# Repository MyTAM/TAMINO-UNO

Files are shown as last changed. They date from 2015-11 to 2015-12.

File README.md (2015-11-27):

# TAMINO-UNO
Docs and Drivers for the TAMINO UNO board
-------------------

[TAMINO-UNO  
*TAMINO UNO (TAMINO01)*](http://www.tuttoamenoshop.it/epages/84141.sf/it_IT/?ObjectPath=/Shops/84141/Products/TAMINO01)

TAMINO UNO is an Arduino(TM) like development board fully compatible, designed in Italy.

License Information
-------------------

The hardware design and firmware are released under [Creative Commons Share-alike 3.0](http://creativecommons.org/licenses/by-sa/3.0/).

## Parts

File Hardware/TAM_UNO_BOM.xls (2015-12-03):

AD | 6x1F-H8.5 | PINHD-1X6 | 1
C1 | 100n | C0603 | 1
C2 | 100n | C0603 | 1
C3 | 100nF | C0603 | 1
C4 | 100n | C0603 | 1
C5 | 100n | C0603 | 1
C6 | 100n | C0603 | 1
C7 | 100nF | C0603 | 1
C8 | 100n | C0603 | 1
C9 | 22p | C0603 | 1
C10 | 22p | C0603 | 1
C11 | 22p | C0603 | 1
C12 | 22p | C0603 | 1
D1 | M7 | DIODE-SMB | 1
D2 | CD1206-S01575 | DIODE-MINIMELF | 1
IC1 | LMV358M | SSO-8 | 1
ICSP | 3x2 | PINHD-2X3 | 1
IOH | 10x1F-H8.5 | PINHD-1X10_ARD | 1
IOL | 8x1F-H8.5 | PINHD-1X8 | 1
L | YELLOW | LED0805 | 1
ON | GREEN | LED0805 | 1
PC1 | 47u | CPOL-EUD | 1
PC2 | 47u | CPOL-EUD | 1
POWER | 8x1F-H8.5 | PINHD-1X8 | 1
Q1 | 12MHz | CRYSTALSM49 | 1
Q2 | 16MHz | CRYSTALSM49 | 1
R1 | 470R | R0603 | 1
R2 | 10k | R0603 | 1
R3 | 10k | R0603 | 1
R4 | 10k | R0603 | 1
R5 | 470R | R0603 | 1
R6 | 470R | R0603 | 1
R7 | 1k | R0603 | 1
R8 | 1k | R0603 | 1
R9 | 10k | R0603 | 1
R10 | 1M | R0603 | 1
R11 | 470R | R0603 | 1
RESET | TS42 BUTTON | TS42 | 1
RX | YELLOW LED | LED0805 | 1
T1 | FDN340P | PMOSSOT23 | 1
T2 | SS8055 | SOT23-EBC | 1
T3 | SS8055 | SOT23-EBC | 1
TX | YELLOW LED | LED0805 | 1
U$1 | CH340G | SSO-14 | 1
U1 | NCP1117ST50T3G | DPAK | 1
U2 | RT9013-33GB | SOT-23-5 | 1
X1 | POWERSUPPLY_DC21MMX | POWERSUPPLY_DC21MMX | 1
X2 | USB-B_TH | PN61729 | 1
Z1 | SOCKET DIL 28 |  | 1
PCB |  |  | 1
ZU4 | ATMEGA328P-PU | ATMEGA328P-PU | 1

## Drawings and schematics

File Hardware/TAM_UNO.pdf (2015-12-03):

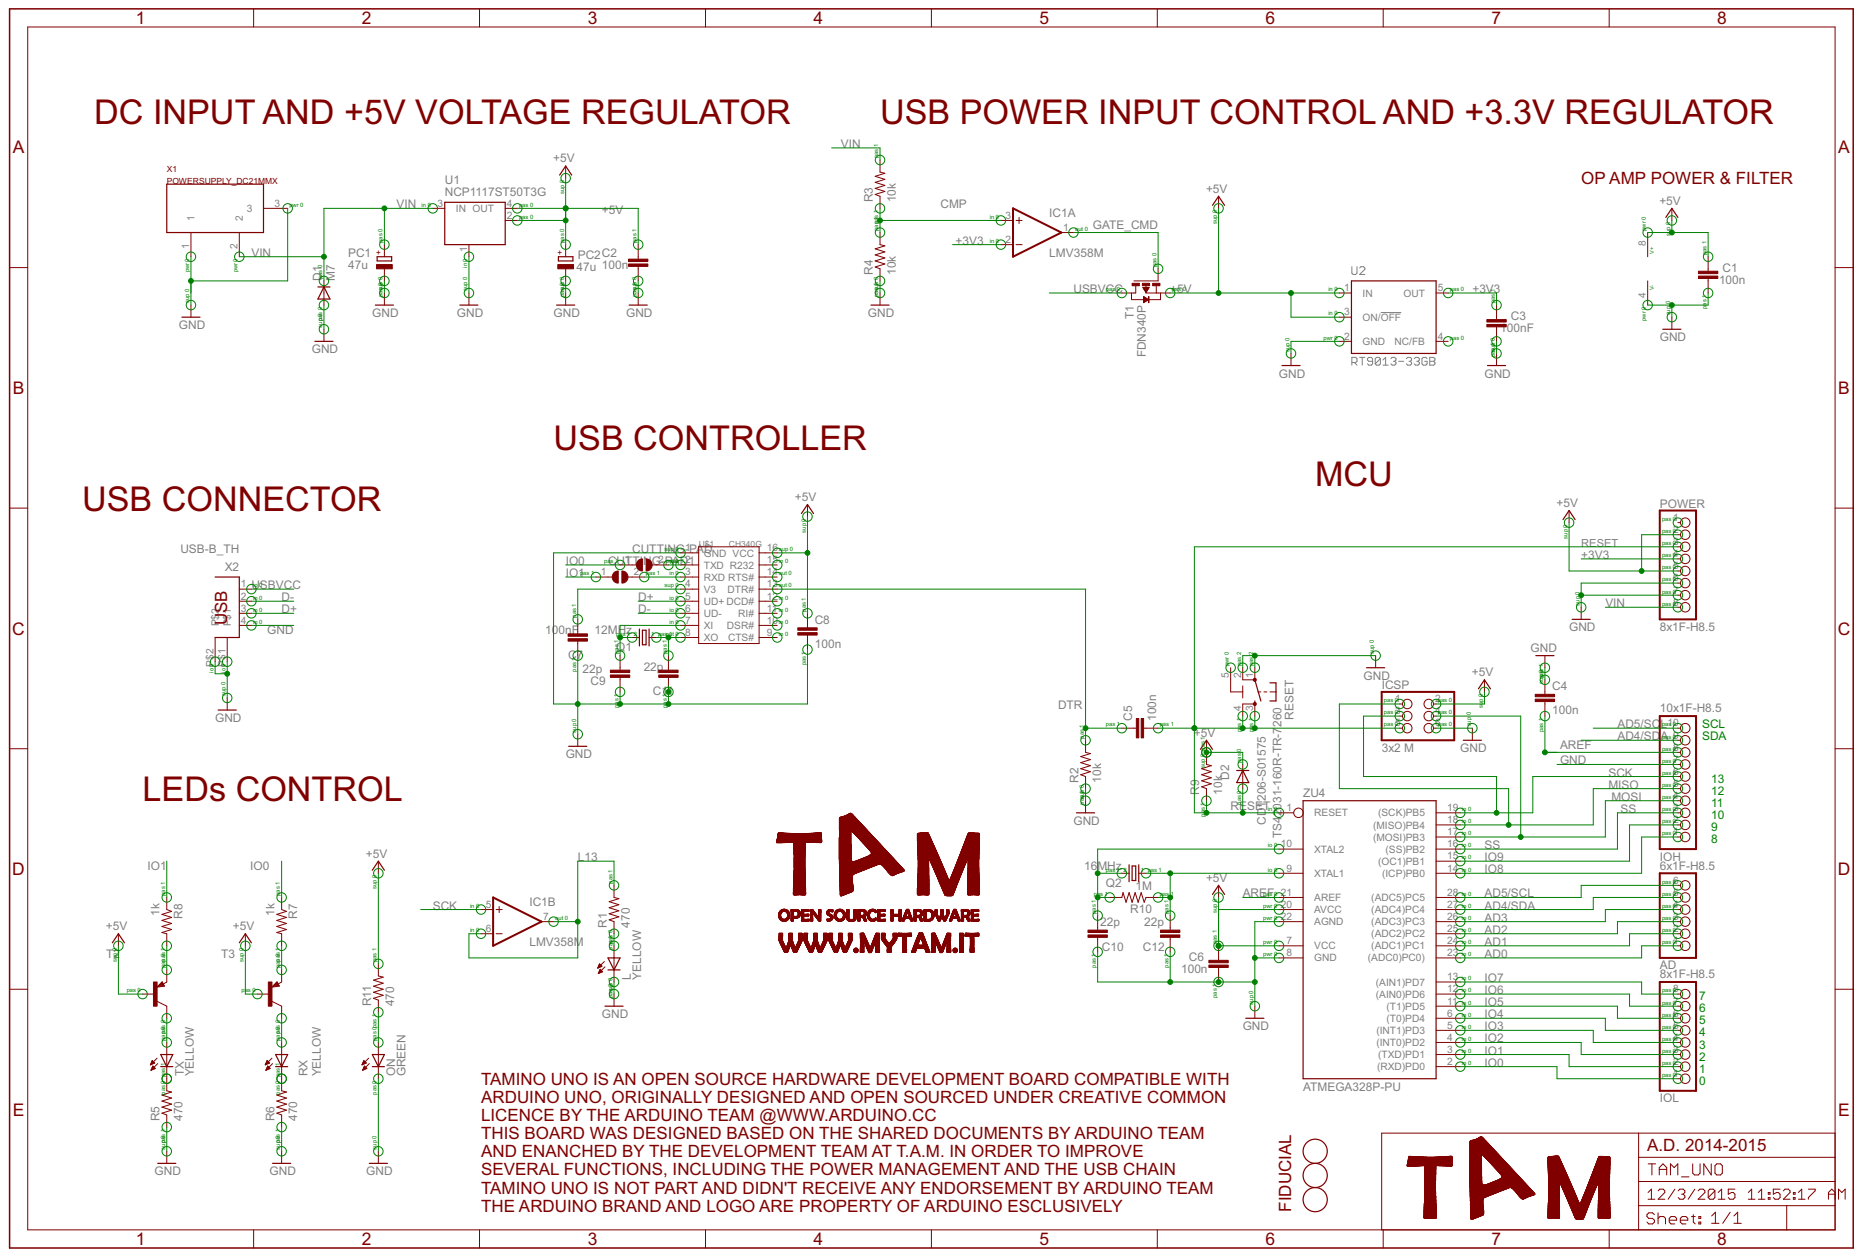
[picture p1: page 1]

pas 1 pas 1

OP AMP POWER & FILTER

pas 0 pas 0 sup 0 sup 0

TAMINO UNO IS AN OPEN SOURCE HARDWARE DEVELOPMENT BOARD COMPATIBLE WITH
ARDUINO UNO, ORIGINALLY DESIGNED AND OPEN SOURCED UNDER CREATIVE COMMON
LICENCE BY THE ARDUINO TEAM @WWW.ARDUINO.CC
THIS BOARD WAS DESIGNED BASED ON THE SHARED DOCUMENTS BY ARDUINO TEAM
AND ENANCHED BY THE DEVELOPMENT TEAM AT T.A.M. IN ORDER TO IMPROVE
SEVERAL FUNCTIONS, INCLUDING THE POWER MANAGEMENT AND THE USB CHAIN
TAMINO UNO IS NOT PART AND DIDN'T RECEIVE ANY ENDORSEMENT BY ARDUINO TEAM
THE ARDUINO BRAND AND LOGO ARE PROPERTY OF ARDUINO ESCLUSIVELY

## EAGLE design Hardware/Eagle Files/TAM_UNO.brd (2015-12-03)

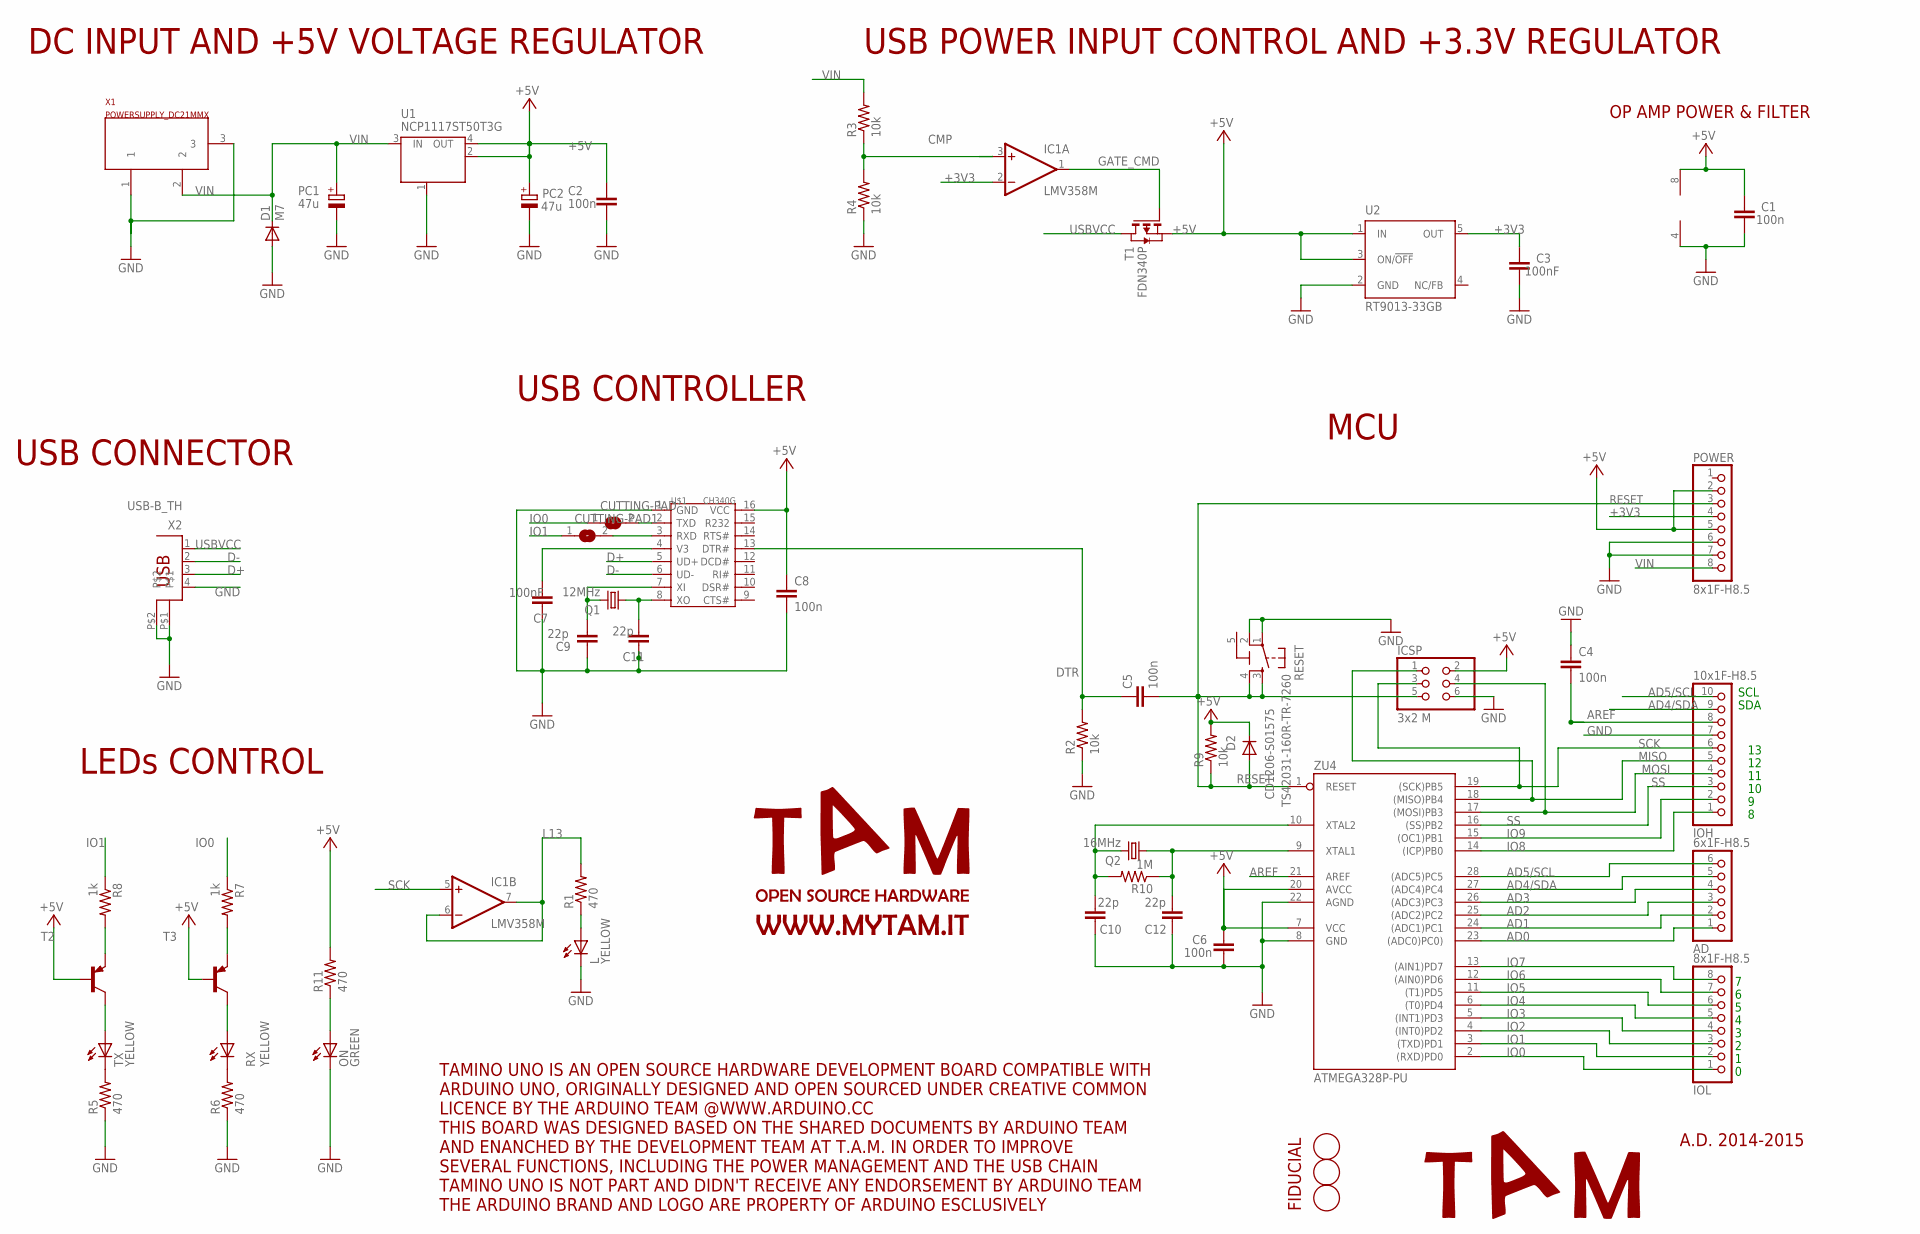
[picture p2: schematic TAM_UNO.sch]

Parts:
AD: 6x1F-H8.5; 1X06
C1, C2, C4, C5, C6, C8: 100n; C0603K
C3, C7: 100nF; C0603K
C9, C10, C11, C12: 22p; C0603K
CUTTING-PAD, CUTTING-PAD1: SJ
D1: M7; SMB
D2: CD1206-S01575; MINIMELF
FD1, FD2, FD3: FIDUCIALMOUNT; FIDUCIA-MOUNT
IC1: LMV358M; SO08
ICSP: 3x2 M; 2X03
IOH: 10x1F-H8.5; 1X10
IOL: 8x1F-H8.5; 1X08
L: YELLOW; CHIP-LED0805
ON: GREEN; CHIP-LED0805
PC1, PC2: 47u; PANASONIC_D
POWER: 8x1F-H8.5; 1X08
Q1: 12MHz; SM49
Q2: 16MHz; SM49
R1, R5, R6, R11: 470; R0603
R2, R3, R4, R9: 10k; R0603
R7, R8: 1k; R0603
R10: 1M; R0603
RESET: TS42031-160R-TR-7260; TS42
RX: YELLOW; CHIP-LED0805
T1: FDN340P; SOT-23
T2, T3: -PNP-SOT23-EBC; SOT23-EBC
TX: YELLOW; CHIP-LED0805
U1: NCP1117ST50T3G; SOT223
U2: RT9013-33GB; SOT23-DBV
U$1: CH340G; SSOP16
X1: POWERSUPPLY_DC21MMX; POWERSUPPLY_DC-21MM
X2: USB-B_TH; PN61729
ZU4: ATMEGA328P-PU; DIL28-3

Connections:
5-GND: RESET.5 (5-GND)
+3V3: C3.2, IC1.2 (-IN), POWER.4, U2.5 (OUT)
+5V: C1.2, C2.2, C6.2, C8.1, D2.C, IC1.8 (V+), ICSP.2, PC2.+, POWER.2, POWER.5, R9.2, R11.2, T1.2 (S), T2.B, T3.B, U1.2 (OUT), U1.4 (OUT), U2.1 (IN), U2.3 (ON/!OFF), U$1.16 (VCC), ZU4.7 (VCC), ZU4.20 (AVCC)
AD0: AD.1, ZU4.23 ((ADC0)PC0))
AD1: AD.2, ZU4.24 ((ADC1)PC1)
AD2: AD.3, ZU4.25 ((ADC2)PC2)
AD3: AD.4, ZU4.26 ((ADC3)PC3)
AD4/SDA: AD.5, IOH.9, ZU4.27 ((ADC4)PC4)
AD5/SCL: AD.6, IOH.10, ZU4.28 ((ADC5)PC5)
AREF: C4.2, IOH.8, ZU4.21 (AREF)
CMP: IC1.3 (+IN), R3.1, R4.2
D+: U$1.5 (UD+), X2.3
D-: U$1.6 (UD-), X2.2
DTR: C5.1, R2.2, U$1.13 (DTR#)
GATE_CMD: IC1.1 (OUT), T1.3 (G)
GND: C1.1, C2.1, C3.1, C4.1, C6.1, C7.2, C8.2, C9.2, C10.2, C11.2, C12.2, D1.A, IC1.4 (V-), ICSP.6, IOH.7, L.C, ON.C, PC1.-, PC2.-, POWER.6, POWER.7, R2.1, R4.1, R5.1, R6.1, RESET.1, RESET.2, U1.1 (GND/ADJ), U2.2 (GND), U$1.1 (GND), X1.1, X1.3, X2.4, X2.P$1, X2.P$2, ZU4.8 (GND), ZU4.22 (AGND)
IO0: CUTTING-PAD.1, IOL.1, R7.1, ZU4.2 ((RXD)PD0)
IO1: CUTTING-PAD1.1, IOL.2, R8.1, ZU4.3 ((TXD)PD1)
IO2: IOL.3, ZU4.4 ((INT0)PD2)
IO3: IOL.4, ZU4.5 ((INT1)PD3)
IO4: IOL.5, ZU4.6 ((T0)PD4)
IO5: IOL.6, ZU4.11 ((T1)PD5)
IO6: IOL.7, ZU4.12 ((AIN0)PD6)
IO7: IOL.8, ZU4.13 ((AIN1)PD7)
IO8: IOH.1, ZU4.14 ((ICP)PB0)
IO9: IOH.2, ZU4.15 ((OC1)PB1)
L13: IC1.6 (-IN), IC1.7 (OUT), R1.2
MISO: ICSP.1, IOH.5, ZU4.18 ((MISO)PB4)
MOSI: ICSP.4, IOH.4, ZU4.17 ((MOSI)PB3)
unnamed: L.A, R1.1
unnamed: C9.1, Q1.2, U$1.7 (XI)
unnamed: ON.A, R11.1
unnamed: C11.1, Q1.1, U$1.8 (XO)
unnamed: R5.2, TX.C
unnamed: R6.2, RX.C
unnamed: R8.2, T2.E
unnamed: R7.2, T3.E
unnamed: T2.C, TX.A
unnamed: RX.A, T3.C
unnamed: C10.1, Q2.2, R10.2, ZU4.10 (XTAL2)
unnamed: C12.1, Q2.1, R10.1, ZU4.9 (XTAL1)
unnamed: CUTTING-PAD.2, U$1.2 (TXD)
unnamed: CUTTING-PAD1.2, U$1.3 (RXD)
RESET: C5.2, D2.A, ICSP.5, POWER.3, R9.1, RESET.3, RESET.4, ZU4.1 (RESET)
SCK: IC1.5 (+IN), ICSP.3, IOH.6, ZU4.19 ((SCK)PB5)
SS: IOH.3, ZU4.16 ((SS)PB2)
USBVCC: T1.1 (D), X2.1
V3: C7.1, U$1.4 (V3)
VIN: D1.C, PC1.+, POWER.8, R3.2, U1.3 (IN), X1.2

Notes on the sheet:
SDA
SCL
DC INPUT AND +5V VOLTAGE REGULATOR
USB POWER INPUT CONTROL AND +3.3V REGULATOR
OP AMP POWER & FILTER
FIDUCIAL
USB CONNECTOR
USB CONTROLLER
MCU
LEDs CONTROL
TAMINO UNO IS AN OPEN SOURCE HARDWARE DEVELOPMENT BOARD COMPATIBLE WITH ARDUINO UNO, ORIGINALLY DESIGNED AND OPEN SOURCED UNDER CREATIVE COMMON LICENCE BY THE ARDUINO TEAM @WWW.ARDUINO.CC THIS BOARD WAS DESIGNED BASED ON THE SHARED DOCUMENTS BY ARDUINO TEAM AND ENANCHED BY THE DEVELOPMENT TEAM AT T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
A.D. 2014-2015

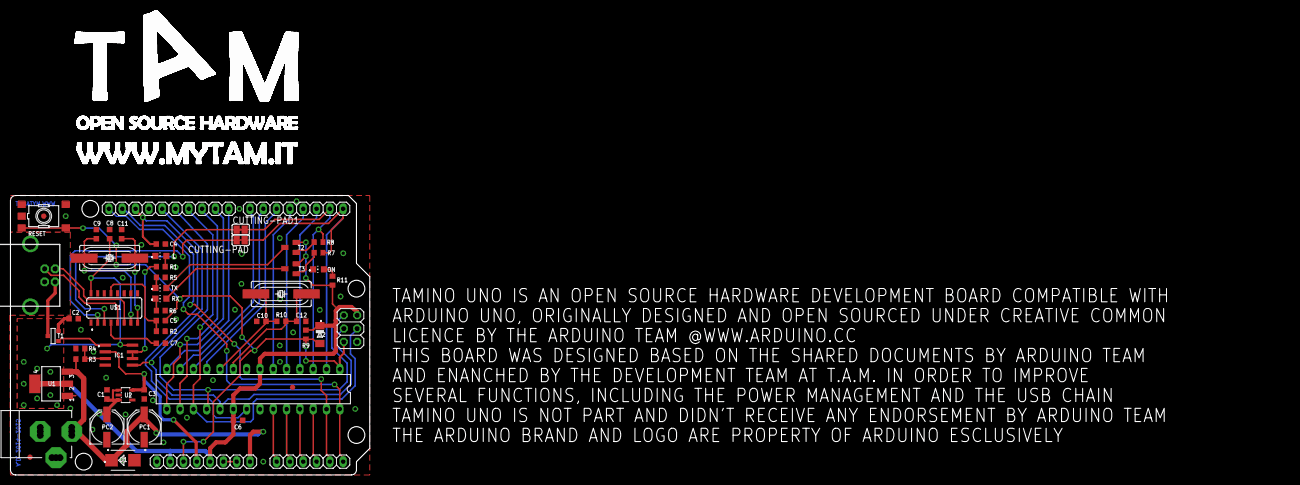
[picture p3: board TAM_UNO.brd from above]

Board: 2 copper layers, 68.6 x 53.3 mm, 54 parts (0 on the bottom side), 48 nets.
